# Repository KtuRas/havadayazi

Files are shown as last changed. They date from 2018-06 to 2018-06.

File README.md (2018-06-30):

<h1>Arduino ile Havada Yazı</h1>

<p>Bu proje Arduino Günü için oluşturulmuştur.</p>
<p>Kendi etrafında dönebilen bir mekanızmaya bağlı 8 ledin, dönüş sırasında belirli bir düzene göre yüksek
    hızda yanıp sönmesi ile havada yazı oluşturma prensibine göre çalışır.
</p>
<p>Mekanizma dururken ledler yanıp sönsede yazıyı göz ile ayırt edebilmek mümkün değildir. Ancak mekanızma döndürülünce 
    ledler havada farklı yerlerde yanıp söneceğinden göz ile algılayabilmek mümkün olmaktadır.    
</p>

## Çalışma Prensibi
<p>Bir harf aşağıdaki şekilde Arduino' nun çıkışına aktarılmıştır. </p>

<table style="width: 197px; height: 207px;">
<tbody>
<tr>
<td style="width: 32px;">A&nbsp;</td>
<td style="width: 32px;">B&nbsp;</td>
<td style="width: 33px;">&nbsp;C</td>
<td style="width: 33px;">&nbsp;D</td>
<td style="width: 33px;">&nbsp;E</td>
<td style="width: 33px;">&nbsp;F</td>
</tr>
<tr>
<td style="width: 32px;">&nbsp;0</td>
<td style="width: 32px;">&nbsp;1</td>
<td style="width: 33px;">&nbsp;1&nbsp;</td>
<td style="width: 33px;">&nbsp;1&nbsp;</td>
<td style="width: 33px;">&nbsp;1&nbsp;</td>
<td style="width: 33px;">&nbsp;0&nbsp;</td>
</tr>
<tr>
<td style="width: 32px;">&nbsp;1&nbsp;</td>
<td style="width: 32px;">&nbsp;0</td>
<td style="width: 33px;">&nbsp;0&nbsp;</td>
<td style="width: 33px;">&nbsp;0</td>
<td style="width: 33px;">&nbsp;0&nbsp;</td>
<td style="width: 33px;">&nbsp;1&nbsp;</td>
</tr>
<tr>
<td style="width: 32px;">&nbsp;1&nbsp;</td>
<td style="width: 32px;">&nbsp;0&nbsp;</td>
<td style="width: 33px;">&nbsp;0&nbsp;</td>
<td style="width: 33px;">&nbsp;0&nbsp;</td>
<td style="width: 33px;">&nbsp;0&nbsp;</td>
<td style="width: 33px;">&nbsp;1&nbsp;</td>
</tr>
<tr>
<td style="width: 32px;">&nbsp;1&nbsp;</td>
<td style="width: 32px;">&nbsp;1&nbsp;</td>
<td style="width: 33px;">&nbsp;1&nbsp;</td>
<td style="width: 33px;">&nbsp;1&nbsp;</td>
<td style="width: 33px;">&nbsp;1&nbsp;</td>
<td style="width: 33px;">&nbsp;1&nbsp;</td>
</tr>
<tr>
<td style="width: 32px;">&nbsp;1&nbsp;</td>
<td style="width: 32px;">&nbsp;0&nbsp;</td>
<td style="width: 33px;">&nbsp;0&nbsp;</td>
<td style="width: 33px;">&nbsp;0&nbsp;</td>
<td style="width: 33px;">&nbsp;0&nbsp;</td>
<td style="width: 33px;">&nbsp;1&nbsp;</td>
</tr>
<tr>
<td style="width: 32px;">&nbsp;1&nbsp;</td>
<td style="width: 32px;">&nbsp;0&nbsp;</td>
<td style="width: 33px;">&nbsp;0&nbsp;</td>
<td style="width: 33px;">&nbsp;0&nbsp;</td>
<td style="width: 33px;">&nbsp;0&nbsp;</td>
<td style="width: 33px;">&nbsp;1&nbsp;</td>
</tr>
<tr>
<td style="width: 32px;">&nbsp;1&nbsp;</td>
<td style="width: 32px;">&nbsp;0&nbsp;</td>
<td style="width: 33px;">&nbsp;0&nbsp;</td>
<td style="width: 33px;">&nbsp;0&nbsp;</td>
<td style="width: 33px;">&nbsp;0&nbsp;</td>
<td style="width: 33px;">&nbsp;1&nbsp;</td>
</tr>
<tr>
<td style="width: 32px;">&nbsp;0&nbsp;</td>
<td style="width: 32px;">&nbsp;0&nbsp;</td>
<td style="width: 33px;">&nbsp;0</td>
<td style="width: 33px;">&nbsp;0&nbsp;</td>
<td style="width: 33px;">&nbsp; 0</td>
<td style="width: 33px;">&nbsp;0&nbsp;</td>
</tr>
</tbody>
</table>
<!-- DivTable.com -->

<p>
    A, B, C, D, E, F ile kodlandmış her sutün için pinlere yazılacak byte değeri şu şekilde
    hesaplanır.
</p>
<span>

        A: 0xE7

        B: 0x90

        C: 0x90

        D: 0x90

        E: 0xE7
</span>

<p>
    Döner mekanizmanın altında belirlenen bir noktaya yerleştirilen mıknatıslar ve bu mıknatısları 
    algılayacak bir reed röle ile yazının hep aynı noktadan başlamasını ve daha okunaklı görünmesini
    sağladık. Ayrıca bu mıktanıs dönen mekanızmanın hızının değişmesi ile yazının genişliğini
    değiştirme olanağı da sağlamaktadır.
</p>

<p>
    Yazılım içerisindeki Seri haberleşme eklentisi ile yazının ve yazının renginin uzaktan 
    değiştirilmesi sağlanmıştır.
</p>

<p>Devre çizimleri /design klasörünün altta mevcuttur.</p>

<p>Örnek çalışma videosuna <a href="https://www.instagram.com/p/BirVfcIHgj9/?taken-by=ieeektu" target="_blank">bağlantıdan 
ulaşabilirsiniz.</a> </p>



<p>...</p>

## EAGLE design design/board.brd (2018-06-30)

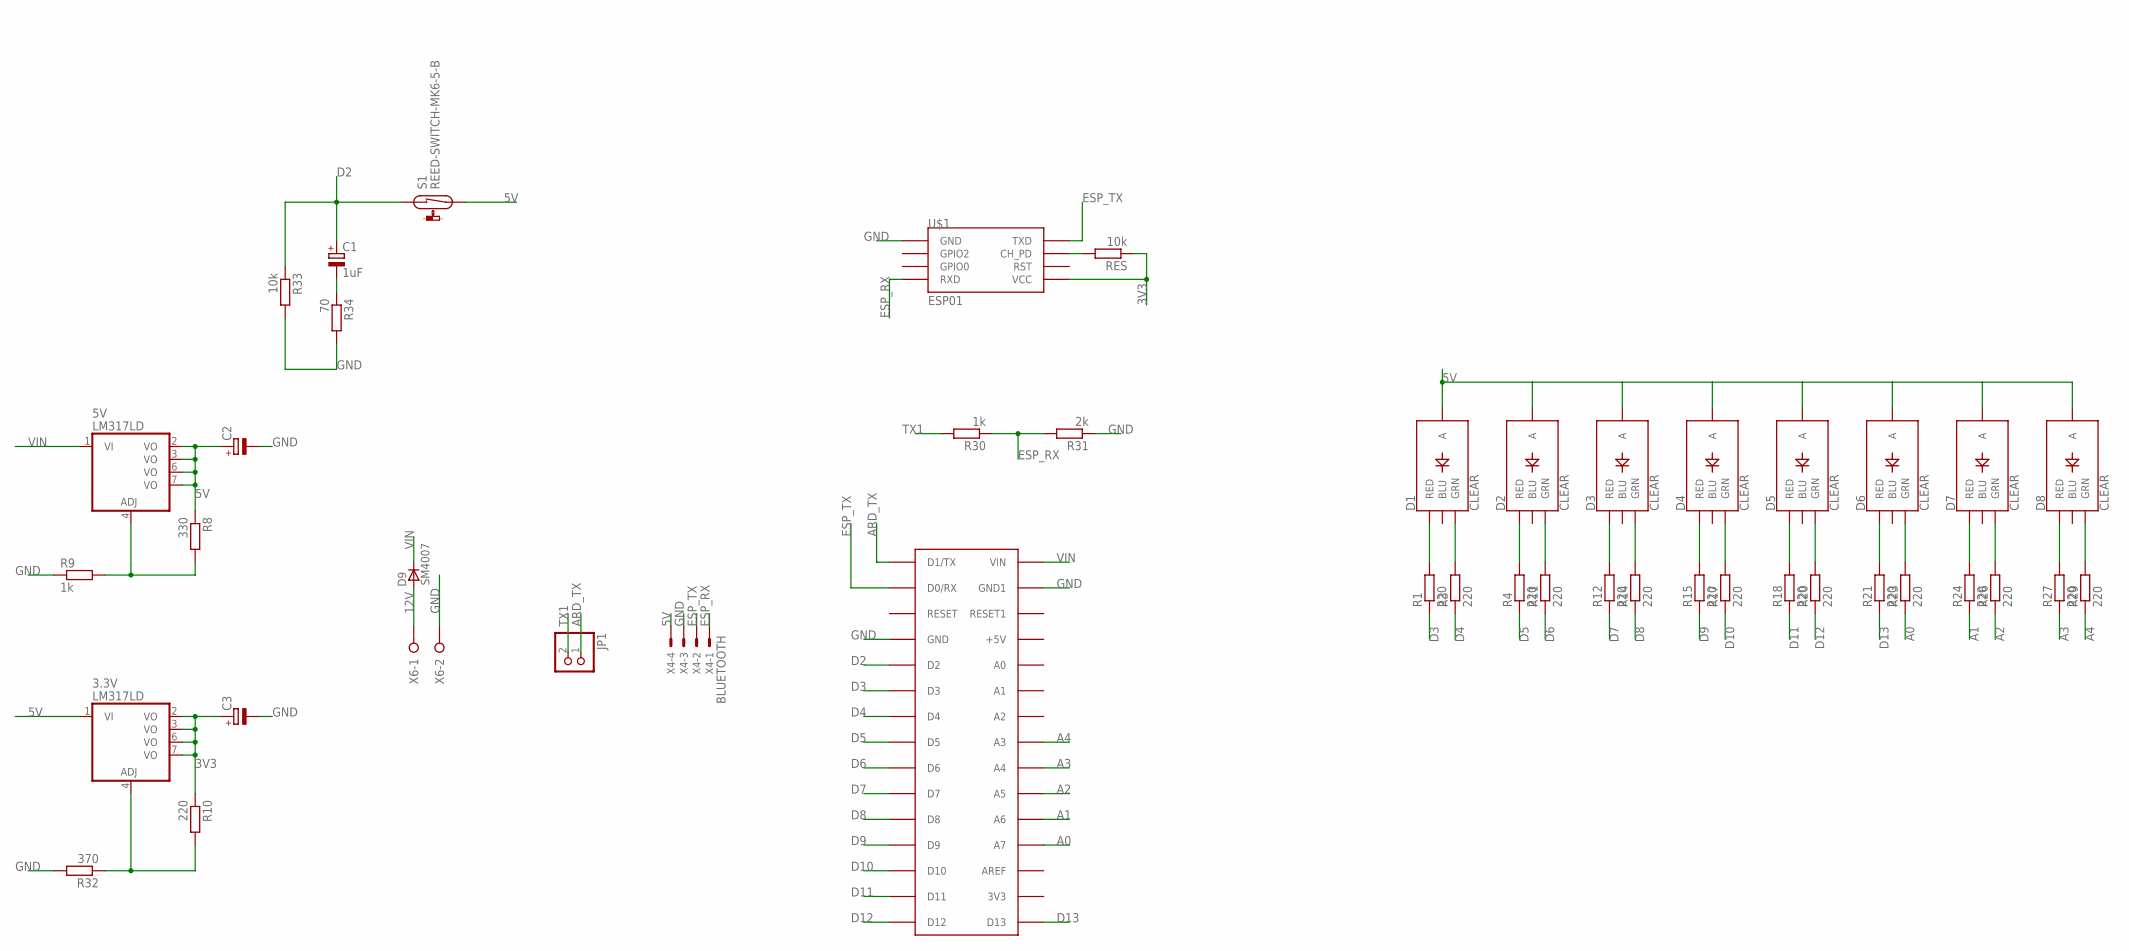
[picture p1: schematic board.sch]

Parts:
3.3V, 5V: LM317LD; SO08
C1: 1uF; E2-4
C2, C3: CPOL-EUE2-5; E2-5
D1, D2, D3, D4, D5, D6, D7, D8: CLEAR; LED-RGB-THRU
D9: SM4007; MELF-MLL41_DO213AB
JP1: PINHD-1X2; 1X02
R1, R3, R4, R10, R11, R12, R14, R15, R17, R18, R20, R21, R23, R24, R26, R27, R29: 220; R1206
R8: 330; R1206
R9, R30: 1k; R1206
R31: 2k; R1206
R32: 370; R1206
R33: 10k; R1206
R34: 70; R1206
RES: 10k; R1206
S1: REED-SWITCH-MK6-5-B; MK6-5
U$1: ESP01
U$2: ARDUINONANO; PDIP-32
X4: BLUETOOTH; 22-23-2041
X6: W237-02P; W237-132

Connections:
3V3: 3.3V.2 (VO), 3.3V.3 (VO), 3.3V.6 (VO), 3.3V.7 (VO), C3.+, R10.1, RES.1, U$1.VCC
5V: 3.3V.1 (VI), 5V.2 (VO), 5V.3 (VO), 5V.6 (VO), 5V.7 (VO), C2.+, D1.2 (A), D2.2 (A), D3.2 (A), D4.2 (A), D5.2 (A), D6.2 (A), D7.2 (A), D8.2 (A), R8.1, S1.2, X4.4
12V: D9.A, X6.1
A0: R23.1, U$2.A7
A1: R24.1, U$2.A6
A2: R26.1, U$2.A5
A3: R27.1, U$2.A4
A4: R29.1, U$2.A3
ARD_TX: JP1.1, U$2.D1/TX
D2: C1.+, R33.1, S1.1, U$2.D2
D3: R1.1, U$2.D3
D4: R3.1, U$2.D4
D5: R4.1, U$2.D5
D6: R11.1, U$2.D6
D7: R12.1, U$2.D7
D8: R14.1, U$2.D8
D9: R15.1, U$2.D9
D10: R17.1, U$2.D10
D11: R18.1, U$2.D11
D12: R20.1, U$2.D12
D13: R21.1, U$2.D13
ESP_RX: R30.1, R31.2, U$1.RX (RXD), X4.1
ESP_TX: U$1.TX (TXD), U$2.D0/RX, X4.2
GND: C2.-, C3.-, R9.1, R31.1, R32.2, R33.2, R34.2, U$1.GND, U$2.GND, U$2.GND1, X4.3, X6.2
unnamed: C1.-, R34.1
unnamed: D1.1 (RED), R1.2
unnamed: RES.2, U$1.CH_PD
unnamed: D1.3 (GRN), R3.2
unnamed: D2.1 (RED), R4.2
unnamed: D2.3 (GRN), R11.2
unnamed: D3.1 (RED), R12.2
unnamed: D3.3 (GRN), R14.2
unnamed: D4.1 (RED), R15.2
unnamed: D4.3 (GRN), R17.2
unnamed: D5.1 (RED), R18.2
unnamed: D5.3 (GRN), R20.2
unnamed: D6.1 (RED), R21.2
unnamed: D6.3 (GRN), R23.2
unnamed: D7.1 (RED), R24.2
unnamed: D7.3 (GRN), R26.2
unnamed: D8.1 (RED), R27.2
unnamed: D8.3 (GRN), R29.2
unnamed: 5V.4 (ADJ), R8.2, R9.2
unnamed: 3.3V.4 (ADJ), R10.2, R32.1
TX1: JP1.2, R30.2
VIN: 5V.1 (VI), D9.C, U$2.VIN

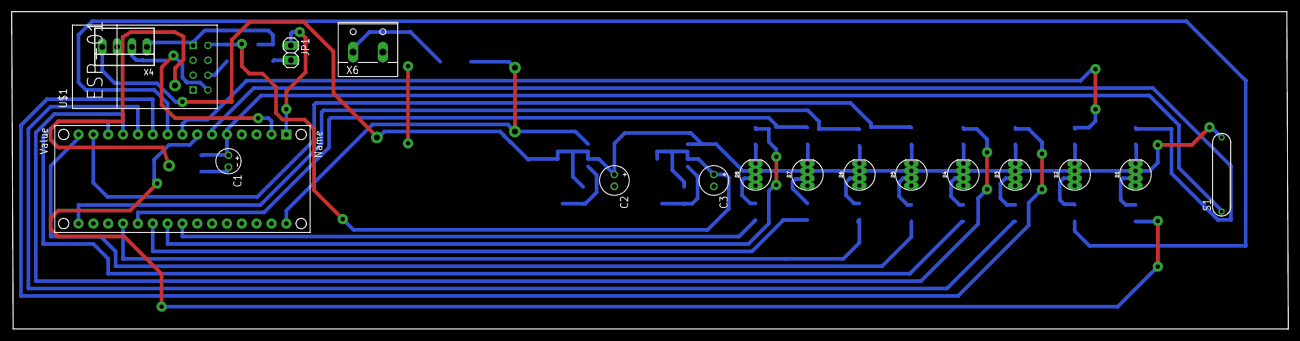
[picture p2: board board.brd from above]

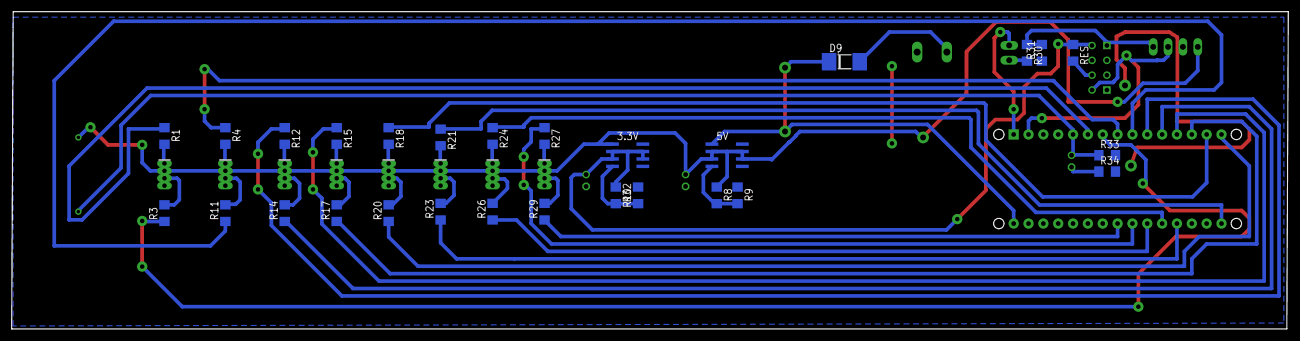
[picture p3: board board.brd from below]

Board: 2 copper layers, 218.4 x 54.3 mm, 45 parts (28 on the bottom side), 46 nets.

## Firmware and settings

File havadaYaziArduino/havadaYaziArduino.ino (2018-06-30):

int ledR[] = {A3, A1, 13, 11, 9, 7, 5, 3};
int ledG[] = {A4, A2, A0, 12, 10, 8, 6, 4};

//char ktueek[] = {
//  0xFF, 0x18, 0x24, 0x42, 0x81, 0x00,
//  0x80, 0x80, 0xFF, 0x80, 0x80, 0x00,
//  0xFE, 0x01, 0x01, 0x01, 0xFE, 0x00,
//  0xFF, 0x91, 0x91, 0x91, 0x81, 0x00,
//  0xFF, 0x91, 0x91, 0x91, 0x81, 0x00,
//  0xFF, 0x18, 0x24, 0x42, 0x81, 0x00
//};

char arduino[] = {
  0x7F, 0x90, 0x90, 0x90, 0x7F, 0x00,
  0xFF, 0x90, 0x98, 0x94, 0x63, 0x00,
  0xFF, 0x81, 0x81, 0x81, 0x7E, 0x00,
  0xFE, 0x01, 0x01, 0x01, 0xFE, 0x00,
  0x00, 0x00, 0xFF, 0x00, 0x00, 0x00,
  0xFF, 0x20, 0x10, 0x08, 0xFF, 0x00,
  0x7E, 0x81, 0x81, 0x81, 0x7E, 0x00,
  0x00, 0x00, 0x00, 0x00, 0x00, 0x00,
  0xFF, 0x81, 0x81, 0x81, 0x7E, 0x00,
  0x7F, 0x90, 0x90, 0x90, 0x7F, 0x00,
  0xC0, 0x20, 0x1F, 0x20, 0xC0, 0x00
};

byte *text;
int cnt = 0;
byte buff[255];
unsigned long lastTime = 0;
int len = 66;
int maxLimit = 20;
bool isRedOn = false, isGreenOn = true;

void setup() {
  // put your setup code here, to run once:

  for (int i = 0; i < 8; i++)
  {
    pinMode(ledR[i], OUTPUT);
    pinMode(ledG[i], OUTPUT);
    digitalWrite(ledG[i], HIGH);
    digitalWrite(ledR[i], HIGH);
  }

  text = (byte *)malloc(len);
  //text = ktueek;
  text = arduino;

  attachInterrupt(0, kesme, RISING);

  Serial.begin(9600);
}

bool started = false;
void kesme()
{
  started = true;
}

void loop() {
  // put your main code here, to run repeatedly:
  if (Serial.available())
  {
    byte c = Serial.read();

    if (c == '#')
    {
      while (!Serial.available());
      c = (byte)Serial.read();
      int i = 0;

      while (c != '#')
      {
        buff[i++] = c;
        while (!Serial.available());
        c = Serial.read();
      }

      len = i;
      delete(text);
      text = (byte *)malloc(i);
      //strncpy(text, buff, i - 1);
      for (int j = 0; j < i; j++)
      {
        text[j] = buff[j];
      }

    } else if (c == '+') {
      while (!Serial.available());
      c = Serial.read();
      byte val = 0;

      if (c == 'R')
      {
        while (!Serial.available());
        val = Serial.read();
        isRedOn = val;
        Serial.print(isRedOn);
      } if (c == 'G')
      {
        while (!Serial.available());
        val = Serial.read();
        isGreenOn = val;
        Serial.print(isGreenOn);
      }
    }
  }

  if (started)
  {
    for (int i = 0; i < len; i++)
    {
      for (int j = 0; j < 8; j++)
      {
        if (isGreenOn)
          digitalWrite(ledG[j], !bitRead(text[i], j));
        if (isRedOn)
          digitalWrite(ledR[j], !bitRead(text[i], j));
      }
      delayMicroseconds(400);
    }

    started = false;
  }
}

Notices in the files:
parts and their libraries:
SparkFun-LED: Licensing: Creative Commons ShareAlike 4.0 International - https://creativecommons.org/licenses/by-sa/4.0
